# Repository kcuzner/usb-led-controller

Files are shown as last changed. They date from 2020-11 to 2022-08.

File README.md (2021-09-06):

# USB-attached LED controller

This is an LED controller for the lights that came with my In-Win A1 Mini-ITX Tower. It came with a simple 12V RGB LED
strip, rather than the now-standard WS2812 addressable LED strips that are so common in today's PCs.

I made one of these **ages** ago for my first self-built computer using all through-hole components and an AVR
microcontroller. It eventually broke after I shorted one of the MOSFETs out on my case when banging around in there
while it was turned on.

This one is a refresh of that idea, with a few additions I've picked up after another decade of tinkering:

 - STM32L042 microcontroller with crystal-less USB capability.
 - Outputs for 12V RGB and 5V WS2812.
 - 2.5" HDD screw pattern for mounting.
 - No secondary side or through-hole components.
 - Driverless HID device implementation.
 - Linux control daemon.
 - Windows control service.

## 2021 Part Shortage notes

 - STM32 can be swapped out for:
   - Silabs EFM32HG family
    - EFM32HG308 in the 24-QFN package has enough timers and UARTs to support the application
   - Microchip AT SAM L22 family
 - FETs are jellybean
 - Regulator might be integrated into uC
 - Level translator has no direct replacement
   - Do I really need the tristate version? Why?
   - The SN74LVC1T04 (inverter, non-tristate) seems available. Could I run this inverted?

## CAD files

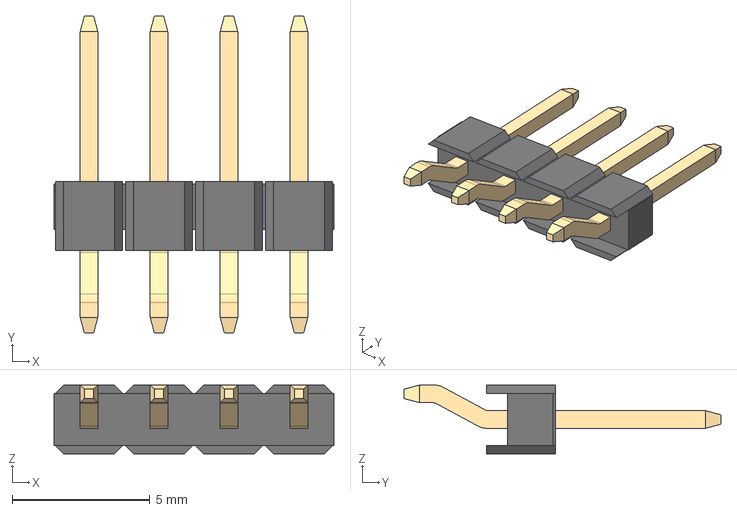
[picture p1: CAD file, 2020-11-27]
step/m20-8890445_asm.stp
10.2 x 11.5 x 2.50 mm
M20-88904_MOULD
M20-889_CONTACT x 4

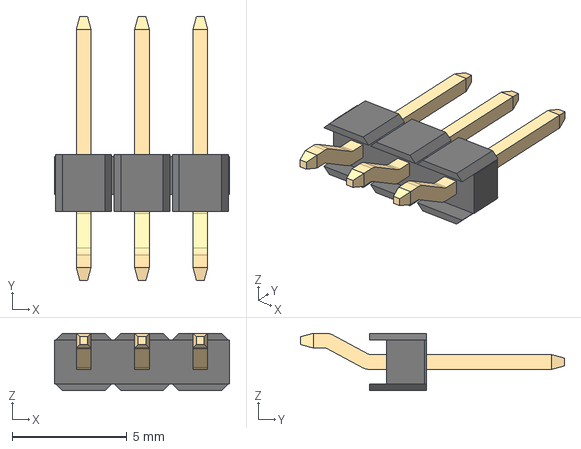
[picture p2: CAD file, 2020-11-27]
step/m20-8890345_asm.stp
7.62 x 11.5 x 2.50 mm
M20-88903_MOULD
M20-889_CONTACT x 3

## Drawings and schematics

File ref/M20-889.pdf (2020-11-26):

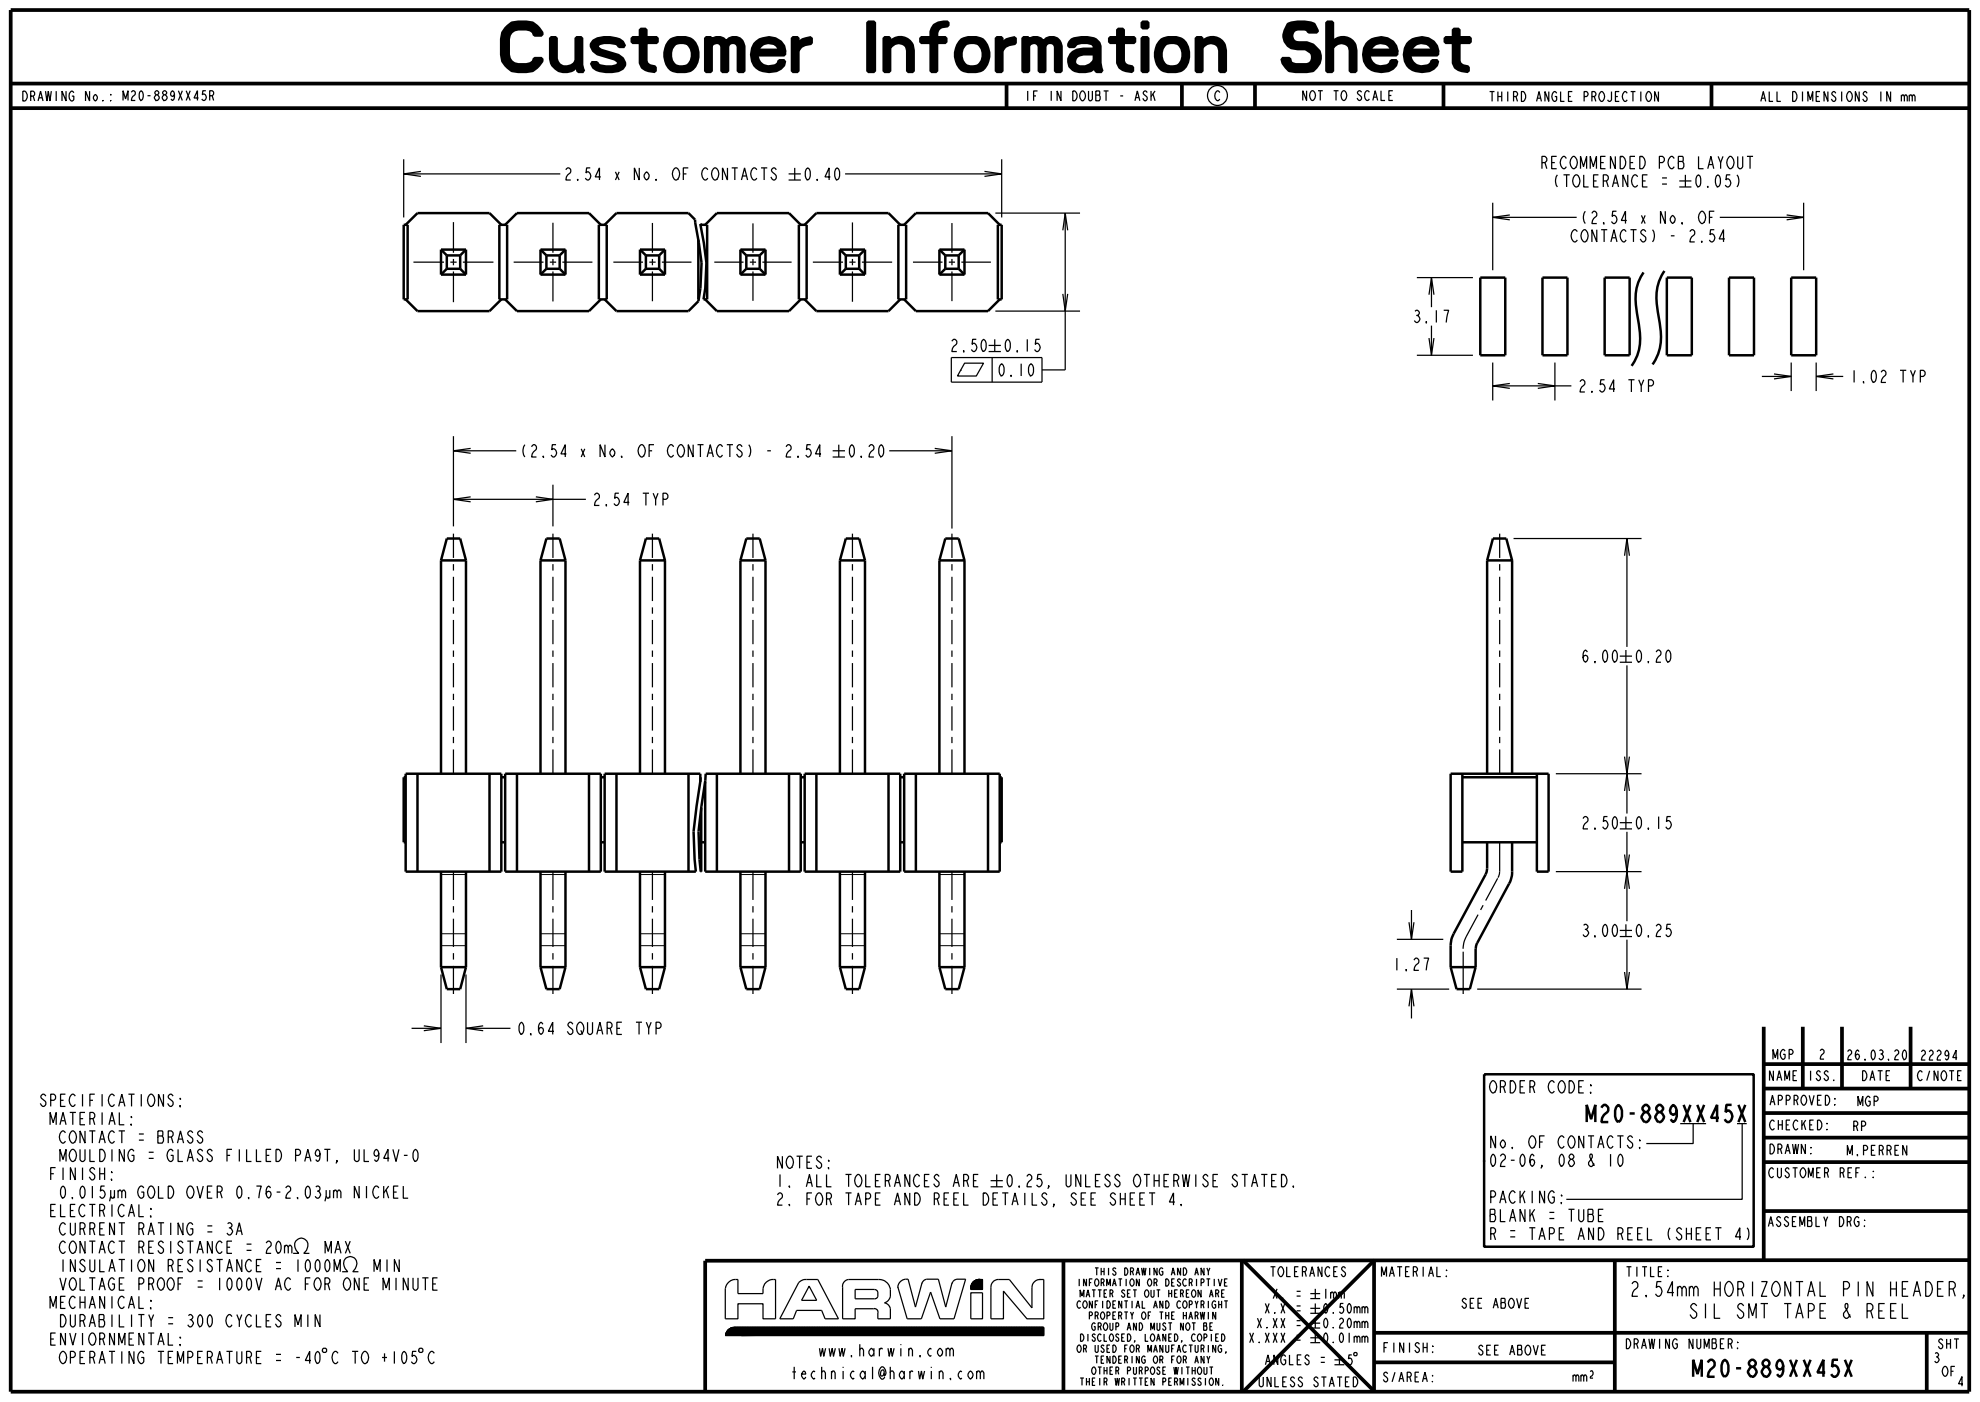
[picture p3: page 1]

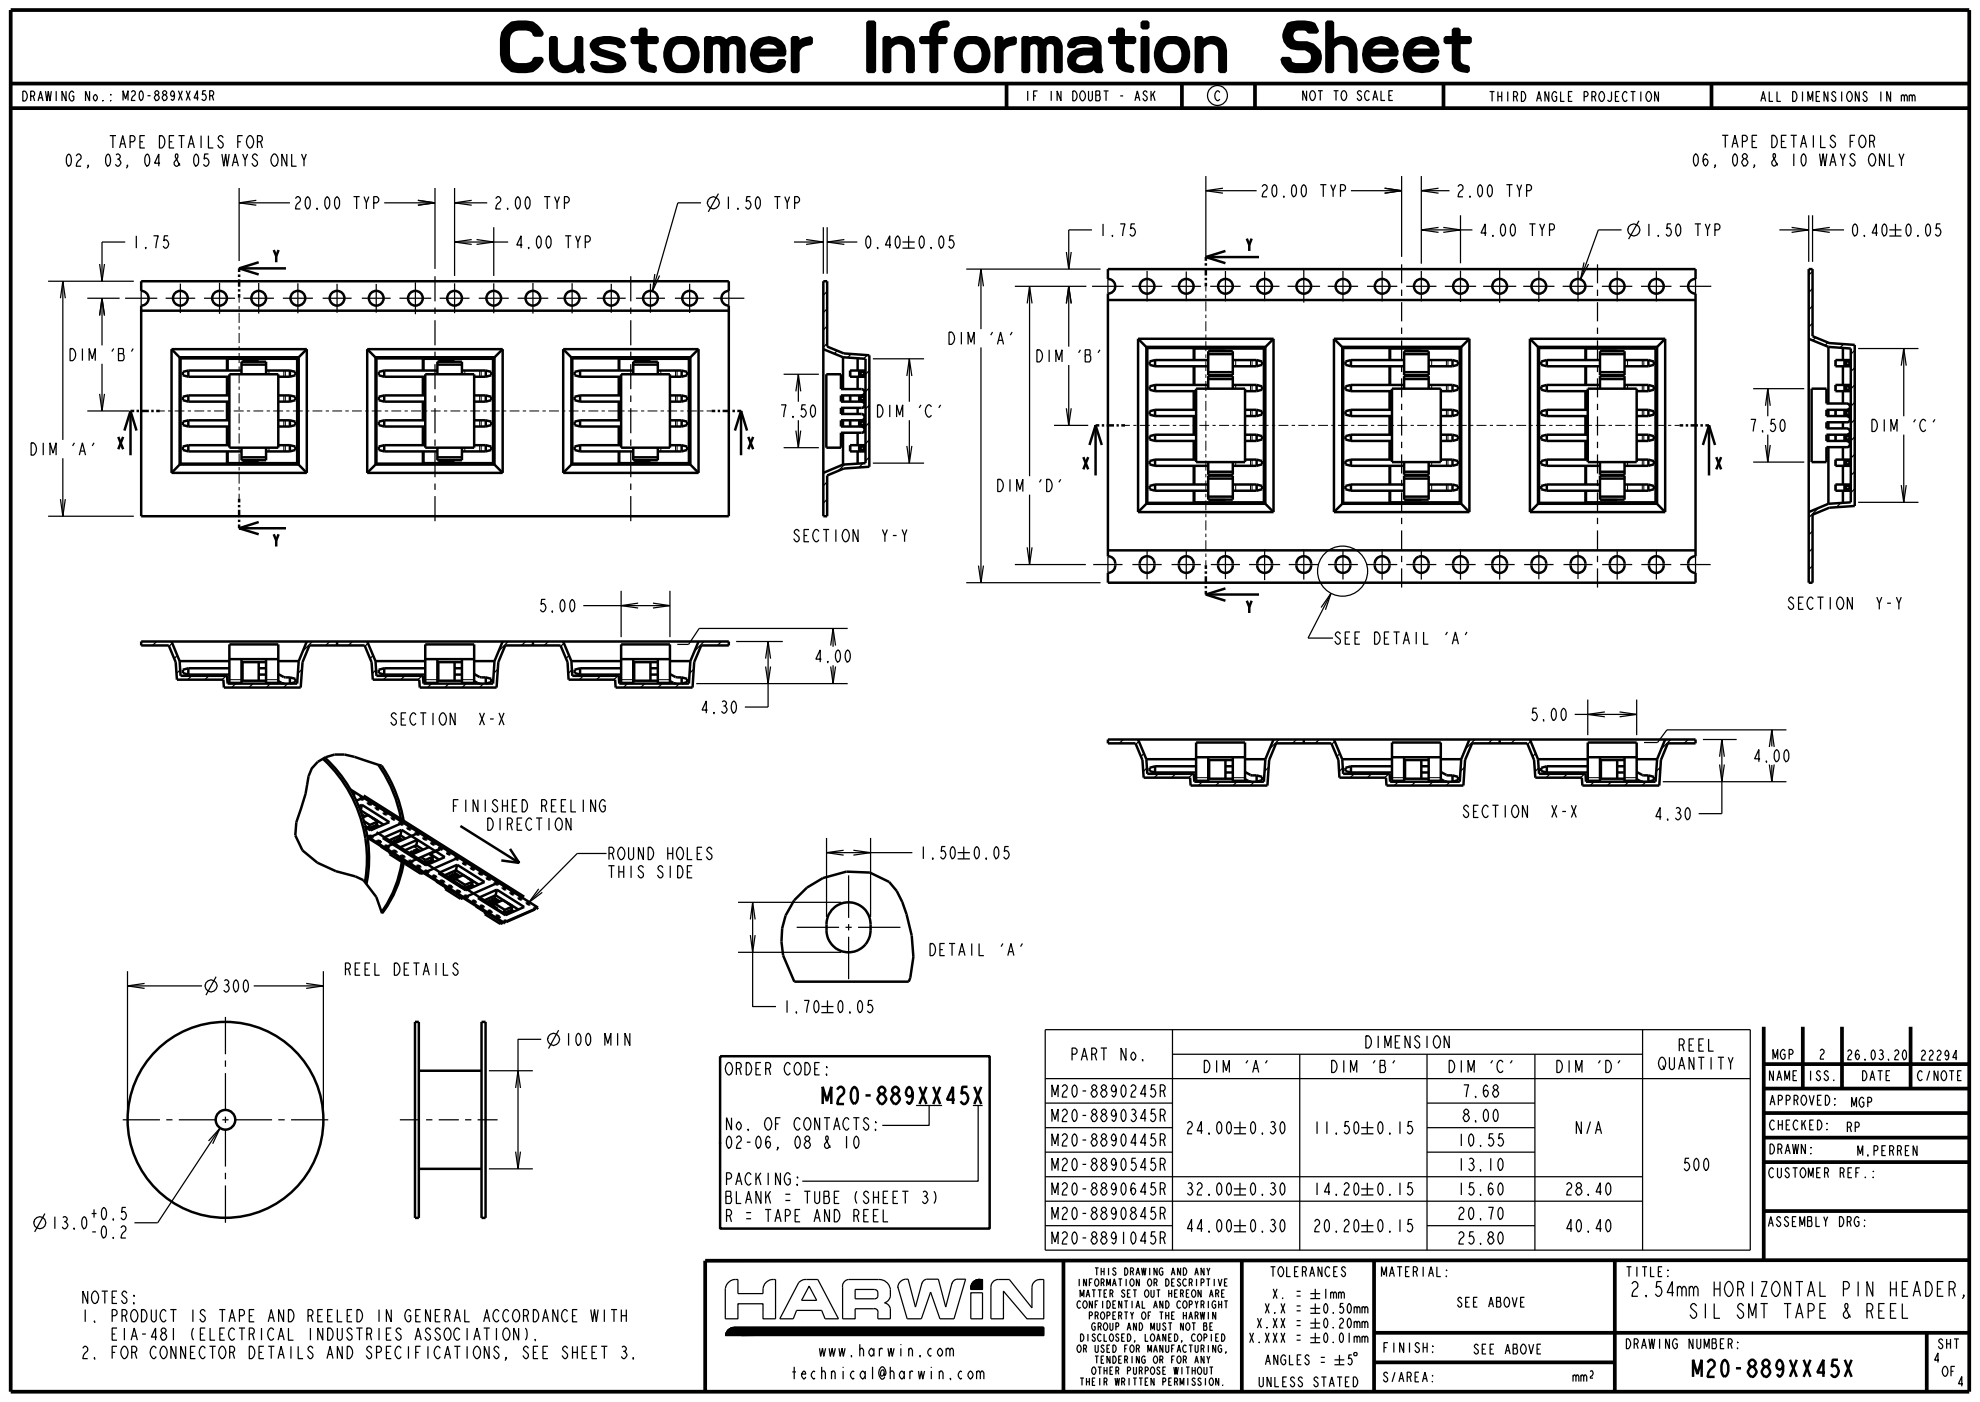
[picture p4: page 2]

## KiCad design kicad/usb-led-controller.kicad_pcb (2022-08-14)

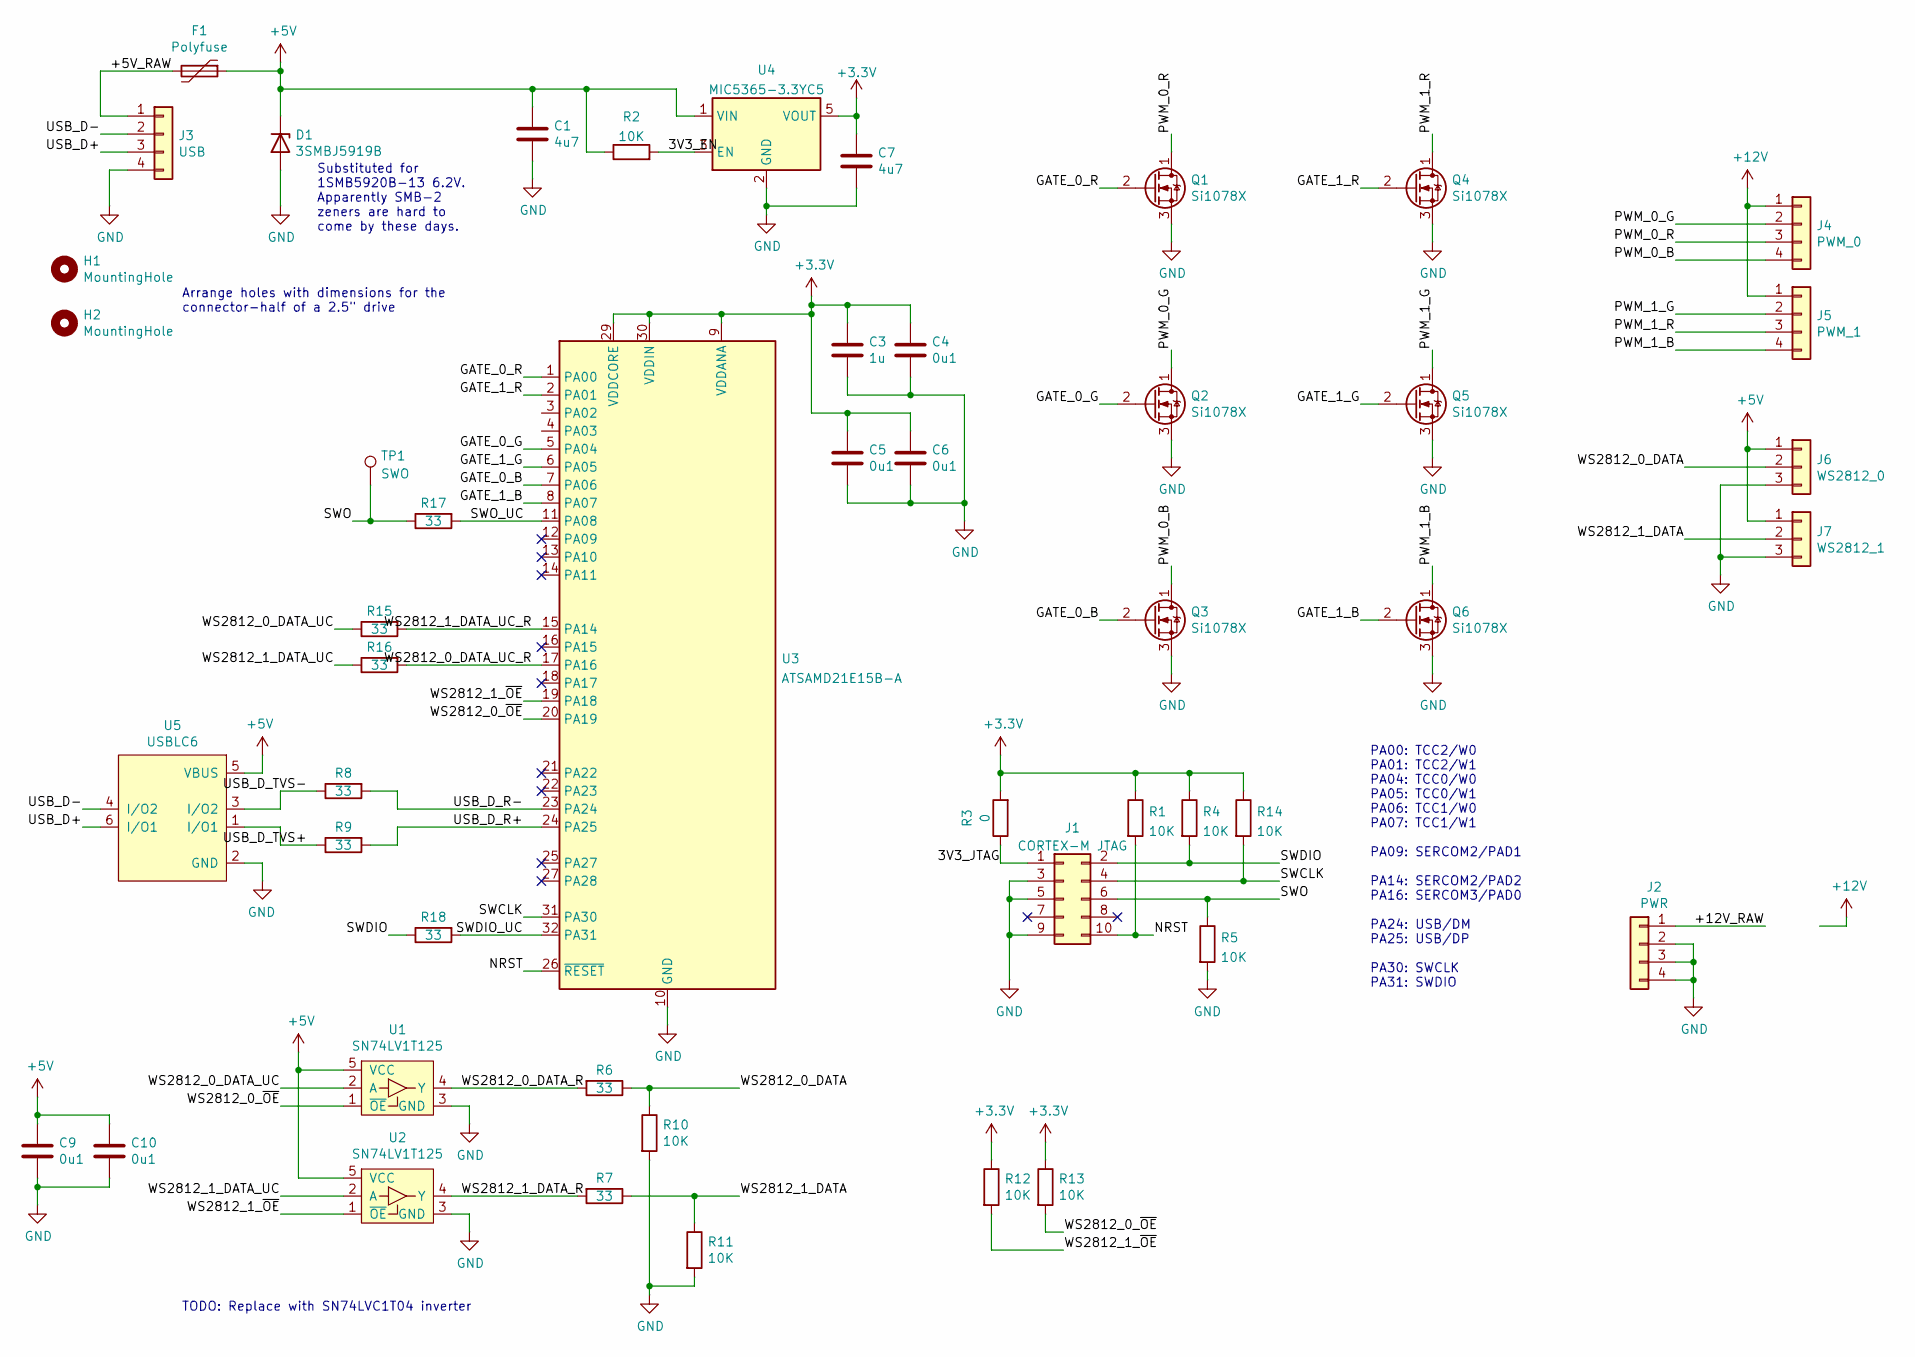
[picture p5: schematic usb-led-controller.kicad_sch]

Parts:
C1, C7: 4u7; C_0603_1608Metric; Part Number 1276-1044-2-ND
C3: 1u; C_0603_1608Metric; Part Number 1276-1102-2-ND
C4, C5, C6, C9, C10: 0u1; C_0402_1005Metric; Part Number 1276-1043-2-ND
D1: 3SMBJ5919B; D_SMB; Part Number 3SMBJ5919B-TPMSTR-ND
F1: Polyfuse; R_1812_4532Metric; Part Number 507-1762-2-ND
H1, H2: MountingHole; MountingHole_3.2mm_M3
J1: CORTEX-M JTAG; CORTEX-SWD-CONNECTOR
J2: PWR; M20-88904; Part Number 952-3233-ND
J3: USB; M20-88904; Part Number 952-3233-ND
J4: PWM_0; M20-88904; Part Number 952-3233-ND
J5: PWM_1; M20-88904; Part Number 952-3233-ND
J6: WS2812_0; M20-88903; Part Number 952-3232-ND
J7: WS2812_1; M20-88903; Part Number 952-3232-ND
Q1, Q2, Q3, Q4, Q5, Q6: Si1078X; SC-89
R1, R2, R4, R5, R14: 10K; R_0402_1005Metric
R3: 0; R_0402_1005Metric
R6, R7, R8, R9, R15, R16, R17, R18: 33; R_0402_1005Metric; Part Number CR0402-JW-330GLFTR-ND
R10, R11, R12, R13: 10K; R_0402_1005Metric; Part Number CR0402-JW-103GLFTR-ND
TP1: SWO; TestPoint_Pad_D1.5mm
U1, U2: SN74LV1T125; SOT-353_SC-70-5; Part Number 296-37173-2-ND
U3: ATSAMD21E15B-A; TQFP-32_7x7mm_P0.8mm
U4: MIC5365-3.3YC5; SOT-353_SC-70-5
U5: USBLC6; SOT-666; Part Number 497-5026-2-ND

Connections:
+3V3: C3.1, C4.1, C5.1, C6.1, C7.1, R1.1, R3.2, R4.1, R12.1, R13.1, R14.1, U3.9 (VDDANA), U3.29 (VDDCORE), U3.30 (VDDIN), U4.5 (VOUT)
+5V: C1.1, C9.1, C10.1, D1.1 (K), F1.1, J6.1, J7.1, R2.1, U1.5 (VCC), U2.5 (VCC), U4.1 (VIN), U5.5 (VBUS)
+12V: J4.1, J5.1; also elsewhere on the board
/3V3_EN: R2.2, U4.3 (EN)
/3V3_JTAG: J1.1, R3.1
/+5V_RAW: F1.2, J3.1
/+12V_RAW: J2.1; also elsewhere on the board
/GATE_0_B: Q3.2 (G), U3.7 (PA06)
/GATE_0_G: Q2.2 (G), U3.5 (PA04)
/GATE_0_R: Q1.2 (G), U3.1 (PA00)
/GATE_1_B: Q6.2 (G), U3.8 (PA07)
/GATE_1_G: Q5.2 (G), U3.6 (PA05)
/GATE_1_R: Q4.2 (G), U3.2 (PA01)
/NRST: J1.10, R1.2, U3.26 (~RESET)
/PWM_0_B: J4.4, Q3.1 (D)
/PWM_0_G: J4.2, Q2.1 (D)
/PWM_0_R: J4.3, Q1.1 (D)
/PWM_1_B: J5.4, Q6.1 (D)
/PWM_1_G: J5.2, Q5.1 (D)
/PWM_1_R: J5.3, Q4.1 (D)
/SWCLK: J1.4, R14.2, U3.31 (PA30)
/SWDIO: J1.2, R4.2, R18.1
/SWDIO_UC: R18.2, U3.32 (PA31)
/SWO: J1.6, R5.1, R17.1, TP1.1
/SWO_UC: R17.2, U3.11 (PA08)
/USB_D+: J3.3, U5.6 (I/O1)
/USB_D-: J3.2, U5.4 (I/O2)
/USB_D_R+: R9.2, U3.24 (PA25)
/USB_D_R-: R8.2, U3.23 (PA24)
/USB_D_TVS+: R9.1, U5.1 (I/O1)
/USB_D_TVS-: R8.1, U5.3 (I/O2)
/WS2812_0_DATA: J6.2, R6.1, R10.1
/WS2812_0_DATA_R: R6.2, U1.4 (Y)
/WS2812_0_DATA_UC: R15.1, U1.2 (A)
/WS2812_0_DATA_UC_R: R16.2, U3.17 (PA16)
/WS2812_0_~OE: R13.2, U1.1 (~OE), U3.20 (PA19)
/WS2812_1_DATA: J7.2, R7.1, R11.1
/WS2812_1_DATA_R: R7.2, U2.4 (Y)
/WS2812_1_DATA_UC: R16.1, U2.2 (A)
/WS2812_1_DATA_UC_R: R15.2, U3.15 (PA14)
/WS2812_1_~OE: R12.2, U2.1 (~OE), U3.19 (PA18)
GND: C1.2, C3.2, C4.2, C5.2, C6.2, C7.2, C9.2, C10.2, D1.2 (A), J1.3, J1.5, J1.9, J2.2, J2.3, J2.4, J3.4, J6.3, J7.3, Q1.3 (S), Q2.3 (S), Q3.3 (S), Q4.3 (S), Q5.3 (S), Q6.3 (S), R5.2, R10.2, R11.2, U1.3 (GND), U2.3 (GND), U3.10 (GND), U3.28 (GND), U4.2 (GND), U5.2 (GND)

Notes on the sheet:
TODO: Replace with SN74LVC1T04 inverter
PA00: TCC2/W0 PA01: TCC2/W1 PA04: TCC0/W0 PA05: TCC0/W1 PA06: TCC1/W0 PA07: TCC1/W1 PA09: SERCOM2/PAD1 PA14: SERCOM2/PAD2 PA16: SERCOM3/PAD0 PA24: USB/DM PA25: USB/DP PA30: SWCLK PA31: SWDIO
Arrange holes with dimensions for the connector-half of a 2.5" drive
Substituted for 1SMB5920B-13 6.2V. Apparently SMB-2 zeners are hard to come by these days.

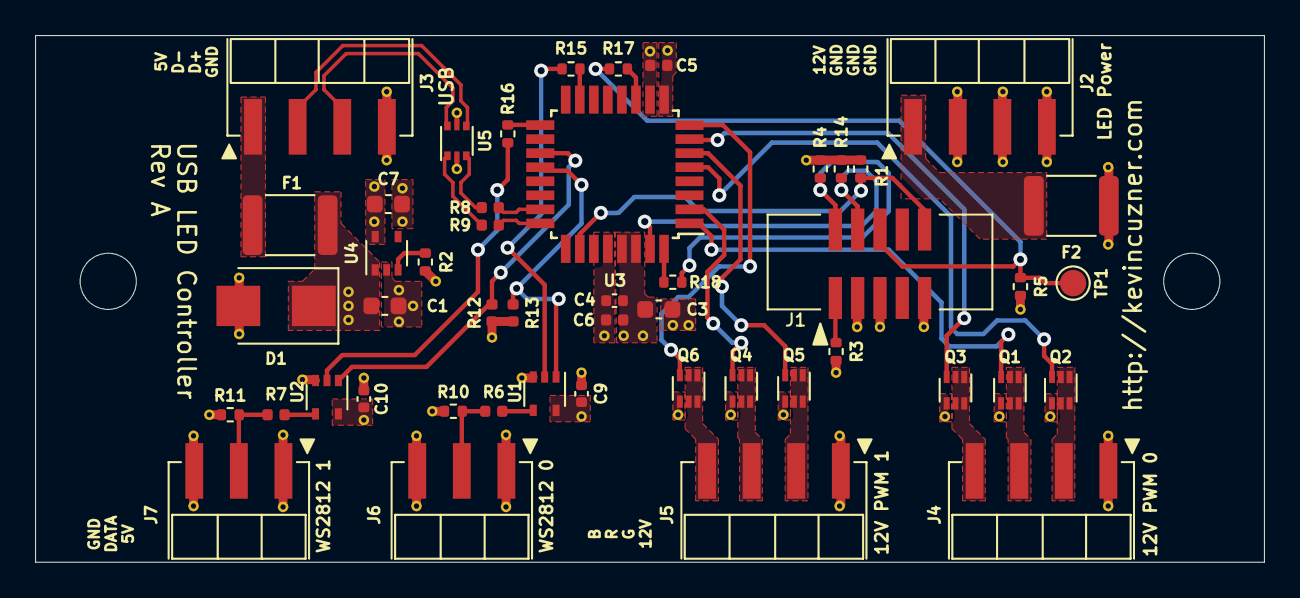
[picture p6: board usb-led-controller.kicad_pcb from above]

Board: 4 copper layers, 70.0 x 30.0 mm, 50 parts (0 on the bottom side), 42 nets.

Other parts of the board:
F2: Polyfuse; R_1812_4532Metric

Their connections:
+12V: F2.1; also elsewhere on the board
/+12V_RAW: F2.2; also elsewhere on the board

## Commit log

2020-11-23 Adding a couple parts to the schematic
    [usb-led-controller.sch]
2020-11-26 Adding initial schematic
    The PWM outputs are driven with the microcontroller PWM. The WS2812
    outputs are driven from UARTS with DMA capability.
    [usb-led-controller.sch]
2020-11-27 Determined board form factor and placed connectors
    [m20-8890345_asm.stp, m20-8890445_asm.stp, usb-led-controller.kicad_pcb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]
2020-11-27 Configuring 4-layer board stackup with netclasses
    [usb-led-controller.kicad_pcb, usb-led-controller.sch]
2020-11-27 Changing microcontroller and redoing WS2812 control
    The QFN package required VIPPO to be easily soldered. I could
    probably have done it without plating-over, but it still requires the
    heat gun and it is currently broken.
    The family was downgraded to an ST32F042, which is a little clunkier
    than the STM32L052 family. It also doesn't have very accessible UARTs
    when USB is being used, so I swapped out the level shifters to tri-state
    ones and used the remaining GPIOs as enables.
    [usb-led-controller.kicad_pcb, usb-led-controller.sch]
2020-11-27 Adding pulldowns on WS2812 outputs
    [usb-led-controller.kicad_pcb, usb-led-controller.sch]
2020-11-28 Added polyfuses and reduced board size
    This is much more reasonable. No need to take up all that space.
    [usb-led-controller.kicad_pcb, usb-led-controller.sch]
2020-11-28 Added power planes to 3rd layer
    [usb-led-controller.kicad_pcb, usb-led-controller.sch]
2020-11-28 Added power planes on top layer and a few traces
    [usb-led-controller.kicad_pcb]
2020-11-28 Cmopleted initial routing
    [usb-led-controller.kicad_pcb, usb-led-controller.sch]
2020-11-28 Cleaning up silkscreen
    [usb-led-controller.kicad_pcb]
2020-11-28 Added some pullups
    [usb-led-controller.kicad_pcb, usb-led-controller.sch]
2020-12-29 Adding text to silkscreen
    [usb-led-controller.kicad_pcb]
2020-12-29 Minor silkscreen cleanup, saving with new kicad
    [usb-led-controller.kicad_pcb]
2021-09-06 Updated part numbers on schematic for building
    This doesn't belong on this branch..
    [usb-led-controller.sch]
2021-09-06 Updating schematic to use an EFM32HG microcontroller
    [usb-led-controller.sch]
2021-09-06 Placed new microcontroller and rearranged capacitors
    [usb-led-controller.kicad_pcb, usb-led-controller.sch]
2021-09-06 Completed routing around the new microcontroller
    [usb-led-controller.kicad_pcb]
2021-09-06 Fixed silkscreen of new components
    [usb-led-controller.kicad_pcb]
2021-09-07 Fixed pad connection on ground layer to be solid
    [usb-led-controller.kicad_pcb]
2022-02-08 Upgrading to Kicad 6
    [usb-led-controller.kicad_pcb, usb-led-controller.kicad_sch, usb-led-controller.sch]
2022-02-20 Changing microcontroller to ATSAMD21E15B
    [usb-led-controller.kicad_pcb, usb-led-controller.kicad_sch]
2022-08-13 Changing programmer header to standard ARM Cortex one
    [usb-led-controller.kicad_pcb, usb-led-controller.kicad_sch]
2022-08-14 Changing FET selection, fixing stackup, adding CYA resistors
    [usb-led-controller.kicad_pcb, usb-led-controller.kicad_sch]
2022-08-14 Gerber out Rev A
    [usb-led-controller-B_Cu.gbr, usb-led-controller-B_Mask.gbr, usb-led-controller-B_Silkscreen.gbr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]
